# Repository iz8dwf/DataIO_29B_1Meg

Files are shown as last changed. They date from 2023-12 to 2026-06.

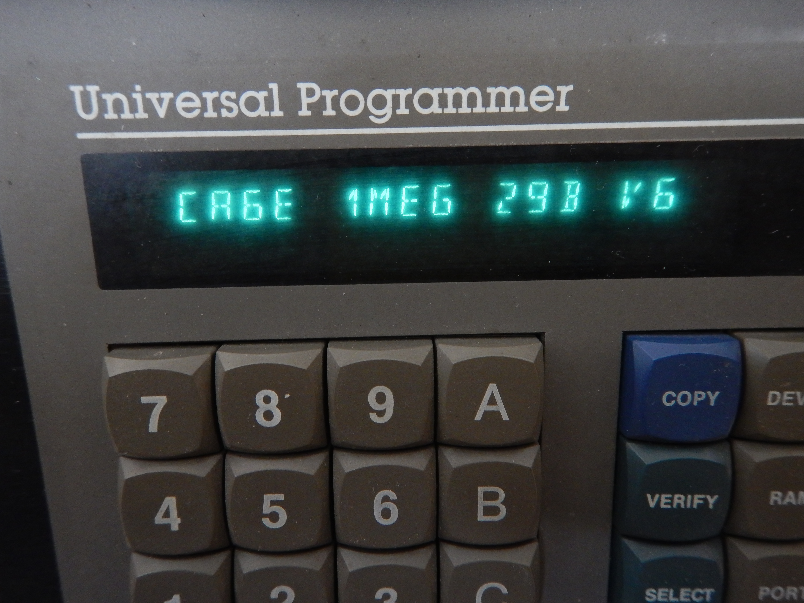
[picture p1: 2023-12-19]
img/DSCN2337.JPG

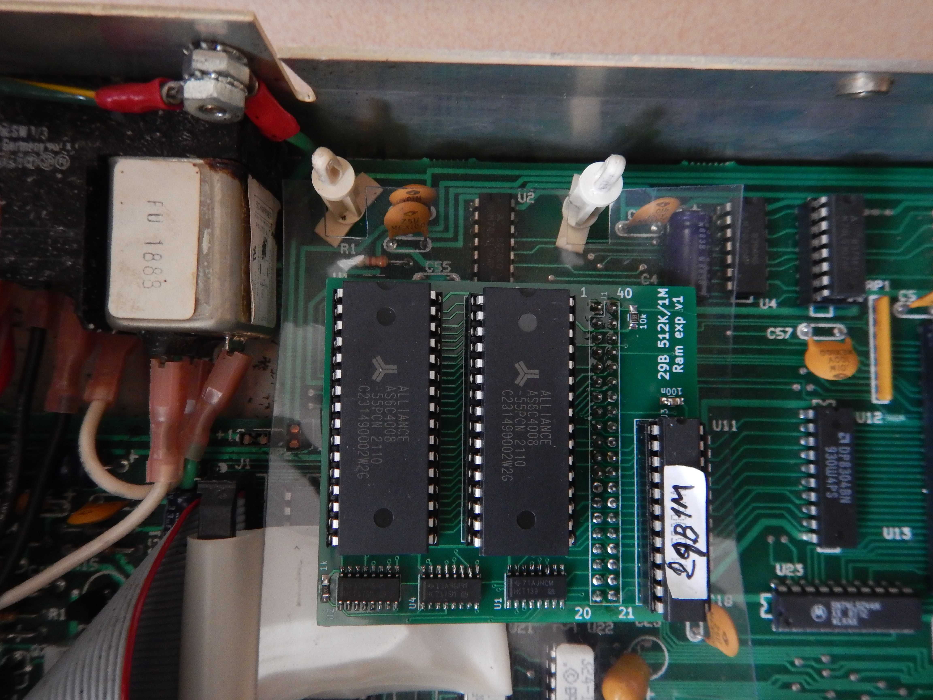
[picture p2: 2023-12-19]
img/DSCN2338.JPG

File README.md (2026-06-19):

# DataIO_29B_1Meg
Data I/O 29B 1MB or 512KB board

This board plugs in the bus connector inside the Data I/O 29B device programmer. It provides 1Mbyte RAM storage or 512K if populating only one SRAM IC.
See the image directory before building and installing it. The pin header connector should have at least 50mm pin length to allow enough vertical clearance from the 29B mainboard.

In `gerber_contrib` I've put a contributed PCB version with mounting holes. Original Data I/O expansion was large and heavier and definitely required mounting holes. If you're concerned about board stability you can use the contributed version. My own board didn't move in years of use anyway.

If you have a model 29A (not B), check the other repository.

USE AT YOUR OWN RISK.

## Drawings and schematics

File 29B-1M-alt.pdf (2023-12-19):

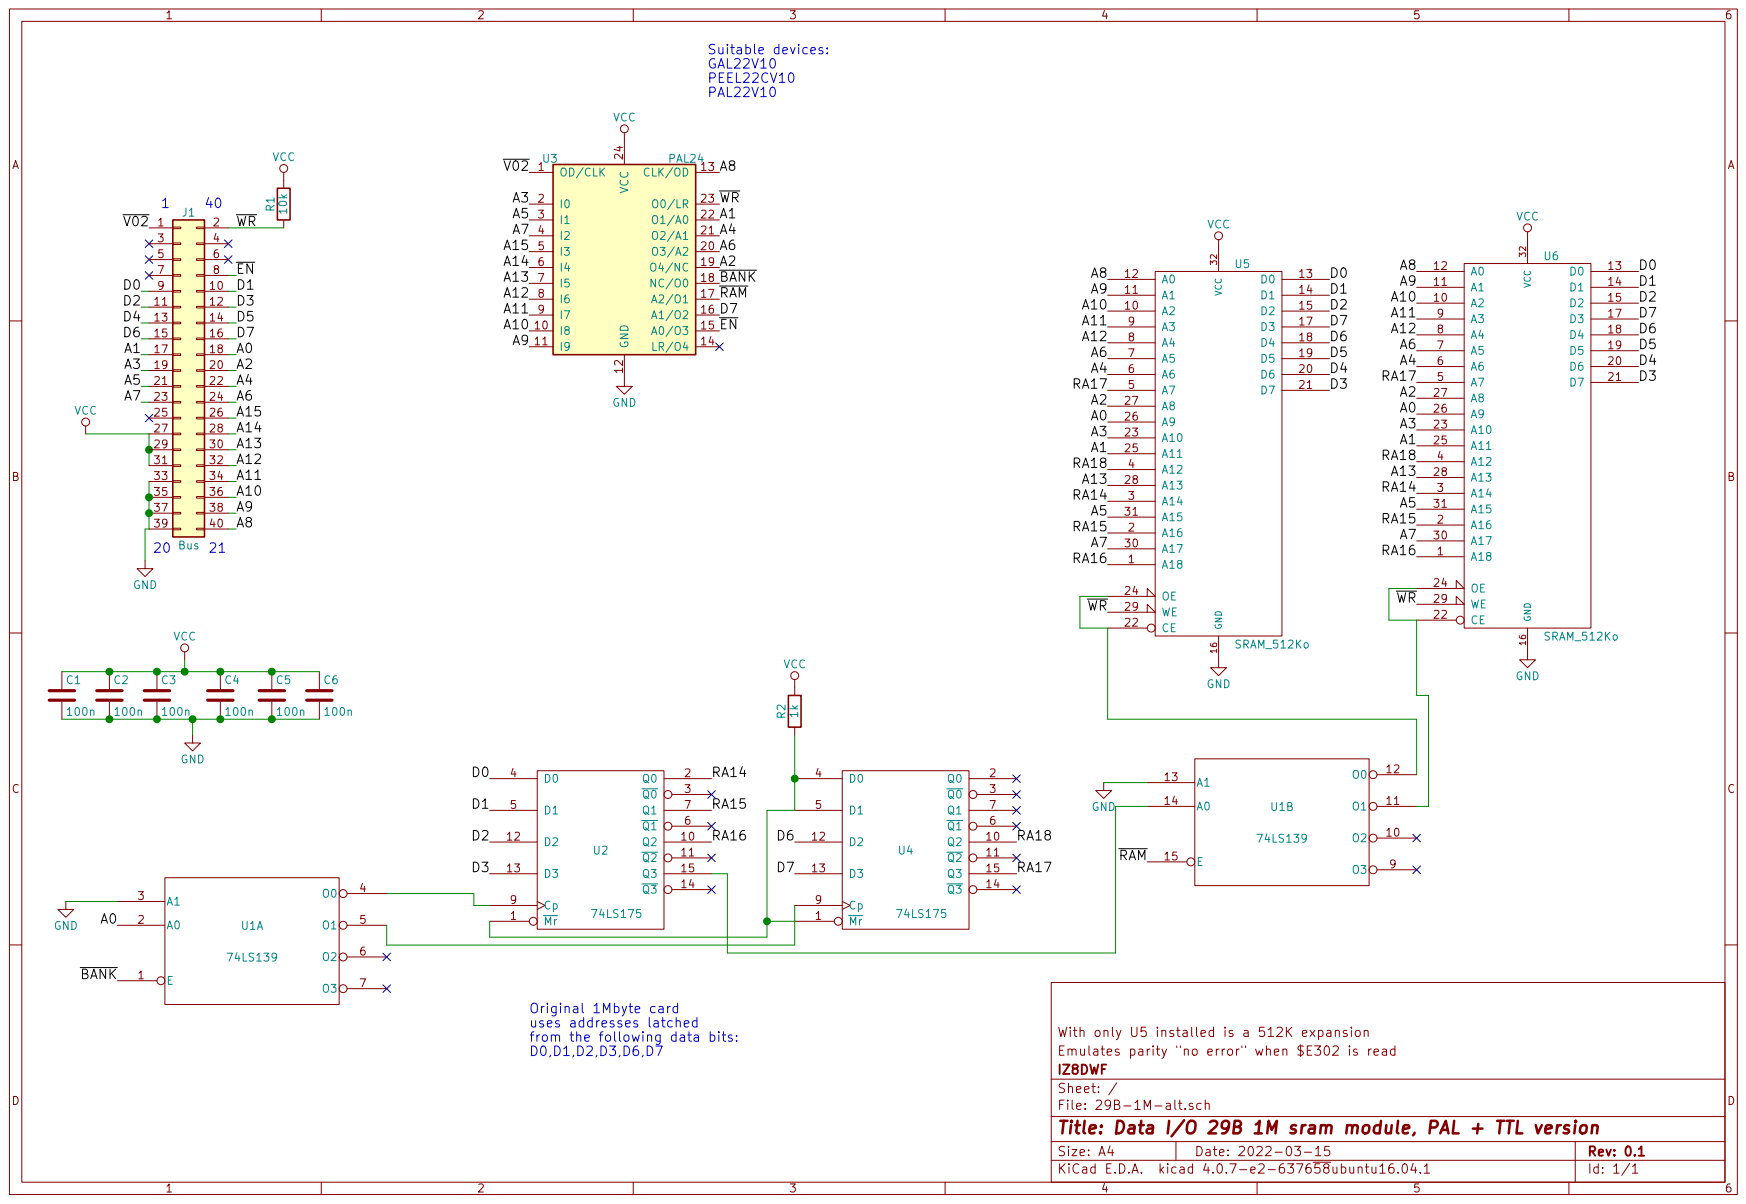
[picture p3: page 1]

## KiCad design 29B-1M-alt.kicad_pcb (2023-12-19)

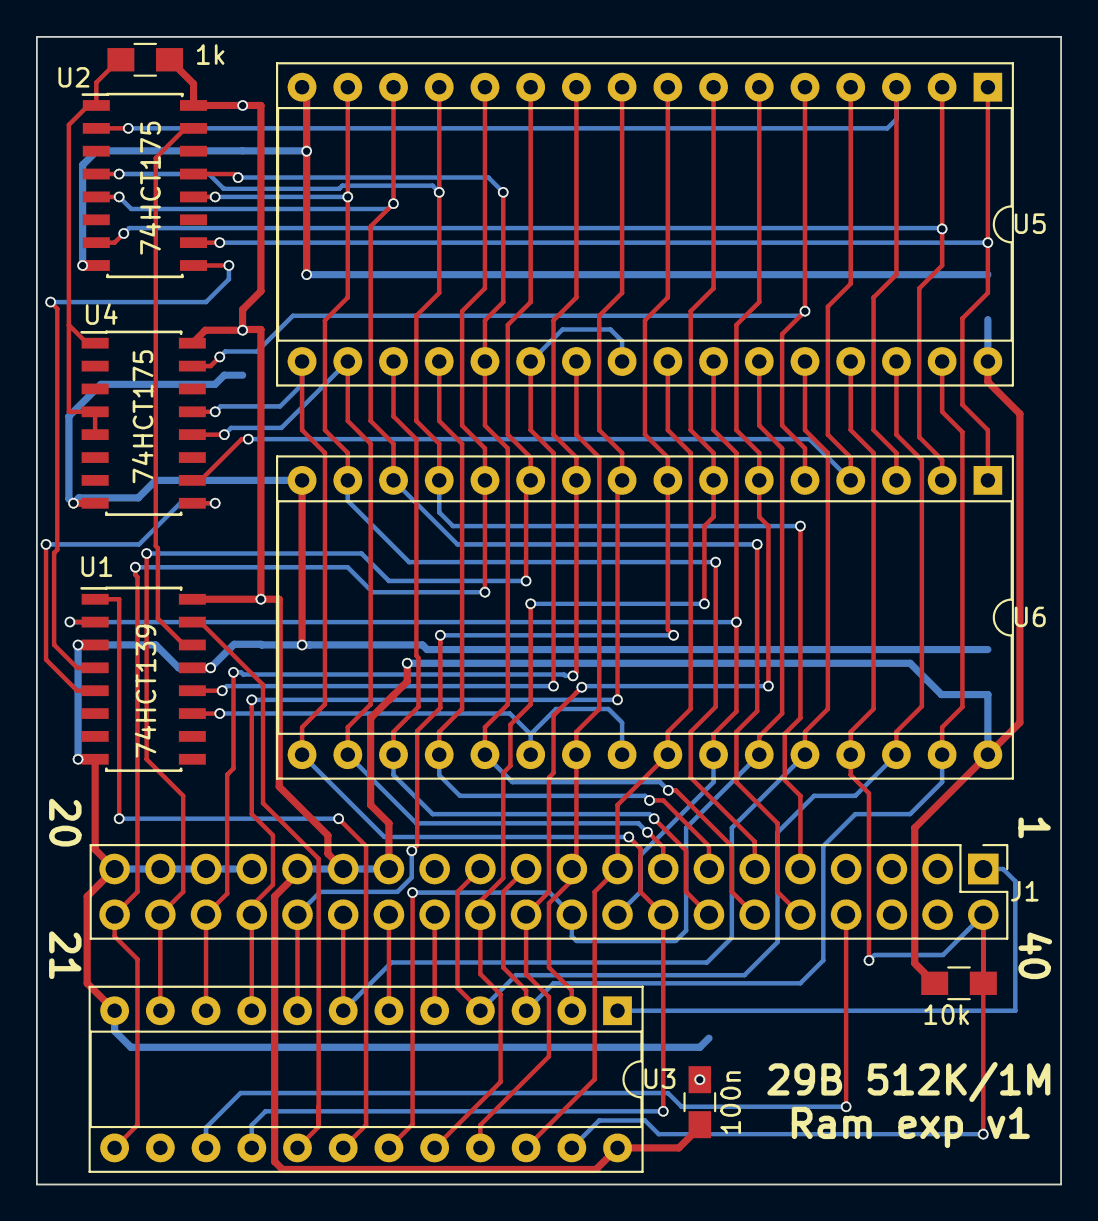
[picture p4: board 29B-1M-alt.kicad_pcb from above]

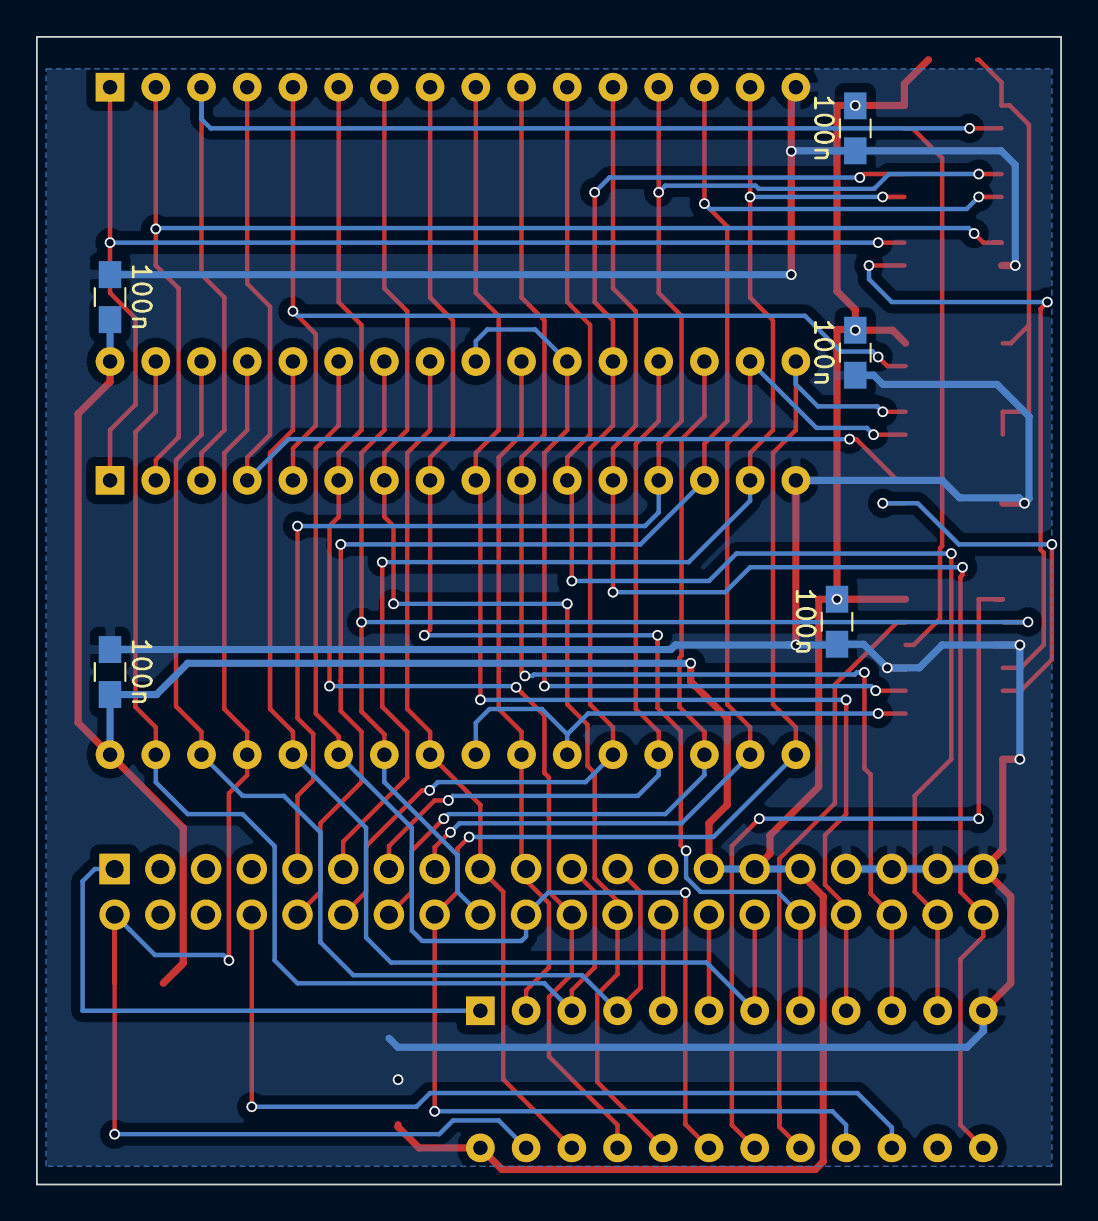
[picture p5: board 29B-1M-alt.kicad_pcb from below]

Board: 2 copper layers, 56.9 x 63.8 mm, 15 parts (5 on the bottom side), 42 nets.

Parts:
C1, C2, C3, C4, C5, C6: 100n; C_0805_HandSoldering
J1: Conn_02x20_Odd_Even; Pin_Header_Straight_2x20_Pitch2.54mm
R1: 10k; R_0805_HandSoldering
R2: 1k; R_0805_HandSoldering
U1: 74HCT139; SOIC-16_3.9x9.9mm_Pitch1.27mm
U2, U4: 74HCT175; SOIC-16_3.9x9.9mm_Pitch1.27mm
U3: PAL24; DIP-24_W7.62mm_Socket
U5, U6: SRAM_512Ko; DIP-32_W15.24mm_Socket

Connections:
/A0: J1.18, U1.2, U5.26, U6.26
/A1: J1.17, U3.22, U5.25, U6.25
/A2: J1.20, U3.19, U5.27, U6.27
/A3: J1.19, U3.2, U5.23, U6.23
/A4: J1.22, U3.21, U5.6, U6.6
/A5: J1.21, U3.3, U5.31, U6.31
/A6: J1.24, U3.20, U5.7, U6.7
/A7: J1.23, U3.4, U5.30, U6.30
/A8: J1.40, U3.13, U5.12, U6.12
/A9: J1.38, U3.11, U5.11, U6.11
/A10: J1.36, U3.10, U5.10, U6.10
/A11: J1.34, U3.9, U5.9, U6.9
/A12: J1.32, U3.8, U5.8, U6.8
/A13: J1.30, U3.7, U5.28, U6.28
/A14: J1.28, U3.6
/A15: J1.26, U3.5
/D0: J1.9, U2.4, U5.13, U6.13
/D1: J1.10, U2.5, U5.14, U6.14
/D2: J1.11, U2.12, U5.15, U6.15
/D3: J1.12, U2.13, U5.21, U6.21
/D4: J1.13, U5.20, U6.20
/D5: J1.14, U5.19, U6.19
/D6: J1.15, U4.12, U5.18, U6.18
/D7: J1.16, U3.16, U4.13, U5.17, U6.17
/RA14: U2.2, U5.3, U6.3
/RA15: U2.7, U5.2, U6.2
/RA16: U2.10, U5.1, U6.1
/RA17: U4.15, U5.5, U6.5
/RA18: U4.10, U5.4, U6.4
/~BANK: U1.1, U3.18
/~EN: J1.8, U3.15
/~RAM: U1.15, U3.17
/~V02: J1.1, U3.1
/~WR: J1.2, R1.1, U3.23, U5.29, U6.29
GND: C1.2, C2.2, C3.2, C4.2, C5.2, C6.2, J1.33, J1.35, J1.37, J1.39, U1.3, U1.8, U1.13, U2.8, U3.12, U4.8, U5.16, U6.16
unnamed: R2.1, U2.1, U4.1, U4.4, U4.5
unnamed: U1.4, U2.9
unnamed: U1.5, U4.9
unnamed: U1.11, U6.22, U6.24
unnamed: U1.12, U5.22, U5.24
unnamed: U1.14, U2.15
VCC: C1.1, C2.1, C3.1, C4.1, C5.1, C6.1, J1.27, J1.29, J1.31, R1.2, R2.2, U1.16, U2.16, U3.24, U4.16, U5.32, U6.32

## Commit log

2023-12-19 first upload
    [29B-1M-alt-B.Cu.gbl, 29B-1M-alt-B.Mask.gbs, 29B-1M-alt-B.SilkS.gbo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]
2026-01-04 added contributed gerbers
